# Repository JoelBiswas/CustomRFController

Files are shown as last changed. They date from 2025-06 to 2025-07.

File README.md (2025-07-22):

# Custom Star Wars RF Controller
This repository contains the files to build a custom RF controller in the shape of the Rebel Alliance Logo from Star Wars. The controller consists of two joysticks, six buttons, and is controlled by an ESP32. This project was created entirely by me for Hack Club's Highway to Undercity event. My plan is to test this device by using to control an [R2-D2 droid that I designed](https://github.com/JoelBiswas/r2d2/tree/main) for the same Hack Club event earlier this summer.

TopView

## Bill of Materials
View the Bill of Materials [here](https://docs.google.com/spreadsheets/d/1eimf_XqeCwkksVUzqHQLZJRxSmD6-AT-35apM8Ljc3Q/edit?usp=sharing)

Screenshot 2025-06-19 at 11 42 58 AM

## The Beginning
The idea for this project came after finishing my last project, an R2-D2 droid controlled with a PS3 controller. I thought that it would be interesting to make my own Star Wars-themed RF transmitter to control the droid with. I hoped that this would provide the robot with much greater range than a Bluetooth-based controller. This project felt perfect as I was looking to start a project that expands my electrical skills. My last project was heavily focused on CAD, so I wanted this project to be more focused on wiring schematic and PCB design. Like the droid, this project is also made for Hack Club's Highway to Undercity event, which provides high school students with grants to build their dream projects.

## About the Controller
The controller consists of two main parts: the PCB and the case. The PCB consists of an ESP32, two MP1584 buck converters, two KY-023 Joystick Modules, six push buttons, and an nRF24L01+ PA/LNA RF Module. It is powered by a 2S LiPo battery that connects to the PCB using a Deans Connector. The case is 3D-printable and houses the battery and PCB. The two joysticks are labeled LS and RS, and the buttons are labeled A, B, X, Y, 1, and 2. An antenna on the PCB extends up through a hole in the top of the case in order to transmit the RF signals.

## Overview of this Repo
**CAD** - Contains the CAD files for the controller, along with images taken from OnShape. <br>
**STLs** - Contains files for each part that needs to be 3D printed <br>
**Print** - Contains the 3d print files for the Flashforge Adventurer 5M <br>
**Electrical** - Contains files from KiCAD for the controller's wiring schematic, custom symbols, custom footprints, and PCB <br>
**Code** - Currently empty but will eventually contain the code for sending RF signals <br>
**JOURNAL.md** - Contains an overview of exactly how I designed and built this robot <br>
**BOM.csv** - A bill of materials for this project in CSV format <br>

## Designing the Robot
Click [here](https://cad.onshape.com/documents/af772411fd2681a1311b7be6/w/e5e3a94108ce63d65661e1b4/e/943c3c2dcbac8496e1ce6b2c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) to view the Onshape document for this project. The electronic design was done in KiCAD.

CAD
PCB

## General Steps for Assembly
1. 3D print each of the files in the STLs folder. The case top and bottom should be printed in orange PLA, and the button should be printed six times in black PLA.
2. Place the LiPo battery into the inserts in the case
3. Place the PCB over the battery on the standoffs. Plug the battery into the Deans connector on the PCB
4. Bolt in the top of the case using an M3 bolt on each side
5. Hot glue the 3D printed button onto the PCB buttons

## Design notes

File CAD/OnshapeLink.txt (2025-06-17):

https://cad.onshape.com/documents/af772411fd2681a1311b7be6/w/e5e3a94108ce63d65661e1b4/e/812a9f2dcd376fd01cbdf196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

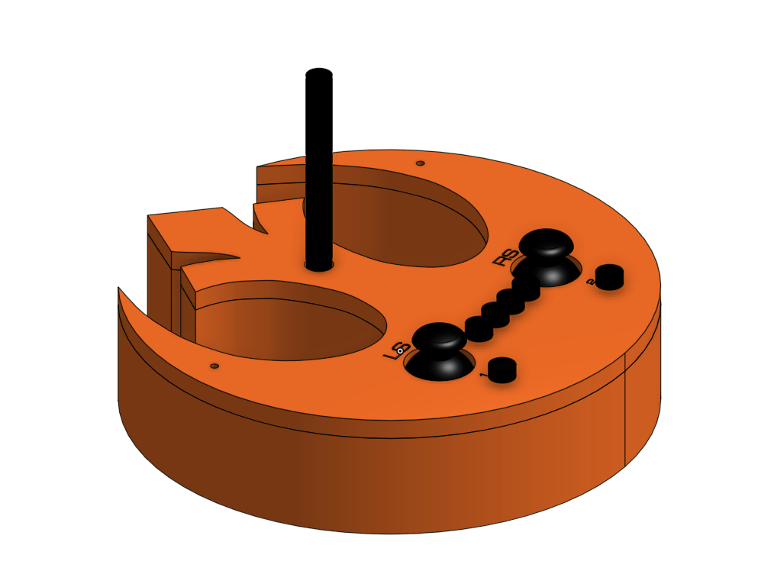
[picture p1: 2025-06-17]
CAD/Images/FrontLeftView.png

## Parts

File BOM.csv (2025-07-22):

Part | Quanitty | Unit Price | Price | Link | CAD Link
nRF24L01+ PA/LNA Radio Module | 1 | $7.99 | $7.99 | https://www.amazon.com/MakerFocus-NRF24L01-Transceiver-Antistatic-Compatible/dp/B01IK78PQA | https://grabcad.com/library/wireless-transceiver-module-2-4g-1100m-nrf24l01-pa-lna-1
ESP-WROOM-32 Microcontroller | 1 | $0.00 | $0.00 | N/A | https://grabcad.com/library/esp32-wroom-32d-devkit-ch340-usb-c-1
Button | 6 | $0.00 | $0.00 | N/A
Joystick | 1 | $6.29 | $6.29 | https://www.amazon.com/Joystick-Control-Sensor-Dual-Axis-Arduino/dp/B0DH2G1PVP?sr=1-5 | https://grabcad.com/library/ky-023-joystick-module-1
2S Lipo | 1 | $11.49 | $11.49 | https://www.amazon.com/OVONIC-Battery-Dean-Style-Connector-Vehicles/dp/B07T7GZ5C2?sr=8-16
MP1584EN Buck Convertor | 1 | $8.29 | $8.29 | https://www.amazon.com/AITRIP-MP1584EN-Converter-Adjustable-Supply/dp/B08DHS5XVK?sr=8-2 | https://grabcad.com/library/detailed-d-sun-mp1584en-dc-dc-step-down-voltage-regulator-1
Decoupling Capacitors | 1 | $9.99 | $9.99 | https://www.amazon.com/dp/B0C1V8Q93P
Male Connector Pins | 1 | $4.99 | $4.99 | https://www.amazon.com/MCIGICM-Header-2-45mm-Arduino-Connector/dp/B07PKKY8BX?sr=8-3
T Connectors | 1 | $6.99 | $6.99 | https://www.amazon.com/FLY-RC-T-Plug-Connectors-Battery/dp/B07BHCFXJZ?sr=8-2 | https://grabcad.com/library/t-plug-deans-connector-male-and-female-connector-1
PCB | 1 | $51.75 | $51.75 | https://cart.jlcpcb.com/quote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
Deburring Tool | 1 | $8.00 | $8.00 | https://www.amazon.com/Deburring-Tool-10Pcs-HSS-Blades/dp/B09376DFYP?sr=8-10
PCB Clamp | 1 | $13.40 | $13.40 | https://www.amazon.com/Noah-Adjustable-Soldering-Desoldering-Rotation/dp/B0CY4DRHWK?sr=8-6
 |  | Total
 |  | $129.18

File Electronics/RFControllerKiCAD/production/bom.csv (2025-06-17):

Designator | Footprint | Quantity | Value | LCSC Part #
5V TO 3.3V1, 7.4V TO 5V1 | MP1584_Module | 2 | ~
BT1 | Deans_Connector | 1 | 7.4V
C1 | C_Disc_D4.3mm_W1.9mm_P5.00mm | 1 | 10 uF
C2 | C_Disc_D4.3mm_W1.9mm_P5.00mm | 1 | 0.1 uF
ESP32 | ESP32_DevKitC_30 | 1 | ~
JOYSTICK1, JOYSTICK2 | KY-023_Module | 2 | ~
RADIO1 | NRF24L01_PA_LNA | 1 | ~
SW1, SW2, SW3, SW4, SW5, SW6 | SW_PUSH_6mm | 6 | SW_Push

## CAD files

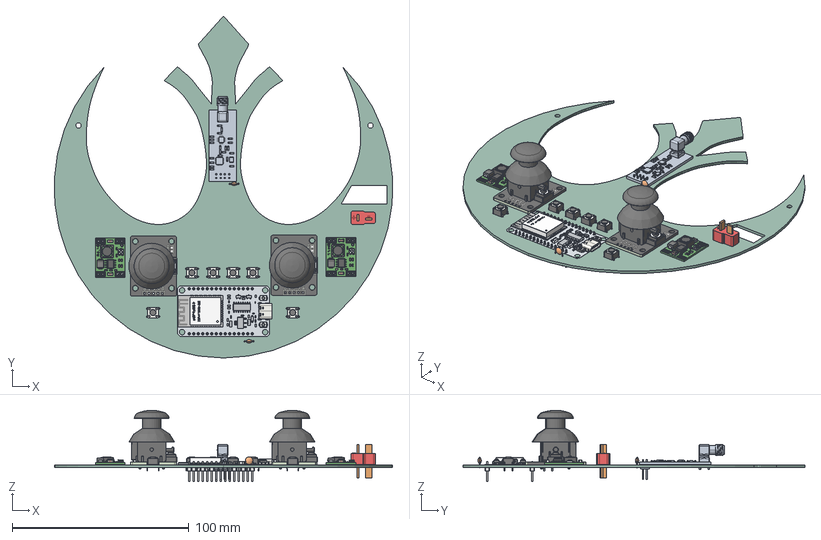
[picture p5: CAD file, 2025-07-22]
Electronics/PCB.step
191.3 x 193.3 x 40.3 mm
SW_PUSH_6mm x 6
main001 x 2
silk-TOP x 2
pins x 2
comp-top x 2
silk-bot x 2
PCB x 3
Thumb-Button x 2
Potentiometer_02 x 2
Baseplate x 2
Tactile-Switch x 2
Case x 2
Potentiometer_01 x 2
Rotator-Unit x 2
SOIC_16_39x99mm_P127mm
SOT_223
USB_C_Receptacle_16P_TopMnt_Horizontal_GCT_USB4105-xx-A
USB_C_Receptacle_16P_TopMnt_Horizontal_GCT_USB4105-xx-A001
USB_C_Receptacle_16P_TopMnt_Horizontal_GCT_USB4105-xx-A002
USB_C_Receptacle_16P_TopMnt_Horizontal_GCT_USB4105-xx-A003
USB_C_Receptacle_16P_TopMnt_Horizontal_GCT_USB4105-xx-A004
USB_C_Receptacle_16P_TopMnt_Horizontal_GCT_USB4105-xx-A005
USB_C_Receptacle_16P_TopMnt_Horizontal_GCT_USB4105-xx-A006
USB_C_Receptacle_16P_TopMnt_Horizontal_GCT_USB4105-xx-A007
USB_C_Receptacle_16P_TopMnt_Horizontal_GCT_USB4105-xx-A008
USB_C_Receptacle_16P_TopMnt_Horizontal_GCT_USB4105-xx-A009
USB_C_Receptacle_16P_TopMnt_Horizontal_GCT_USB4105-xx-A010
USB_C_Receptacle_16P_TopMnt_Horizontal_GCT_USB4105-xx-A011
USB_C_Receptacle_16P_TopMnt_Horizontal_GCT_USB4105-xx-A012
USB_C_Receptacle_16P_TopMnt_Horizontal_GCT_USB4105-xx-A013
USB_C_Receptacle_16P_TopMnt_Horizontal_GCT_USB4105-xx-A014
USB_C_Receptacle_16P_TopMnt_Horizontal_GCT_USB4105-xx-A015
USB_C_Receptacle_16P_TopMnt_Horizontal_GCT_USB4105-xx-A016
USB_C_Receptacle_16P_TopMnt_Horizontal_GCT_USB4105-xx-A017
USB_C_Receptacle_16P_TopMnt_Horizontal_GCT_USB4105-xx-A018
USB_C_Receptacle_16P_TopMnt_Horizontal_GCT_USB4105-xx-A019
USB_C_Receptacle_16P_TopMnt_Horizontal_GCT_USB4105-xx-A020
USB_C_Receptacle_16P_TopMnt_Horizontal_GCT_USB4105-xx-A021
USB_C_Receptacle_16P_TopMnt_Horizontal_GCT_USB4105-xx-A022
USB_C_Receptacle_16P_TopMnt_Horizontal_GCT_USB4105-xx-A023
USB_C_Receptacle_16P_TopMnt_Horizontal_GCT_USB4105-xx-A024
USB_C_Receptacle_16P_TopMnt_Horizontal_GCT_USB4105-xx-A025
USB_C_Receptacle_16P_TopMnt_Horizontal_GCT_USB4105-xx-A026
USB_C_Receptacle_16P_TopMnt_Horizontal_GCT_USB4105-xx-A027
USB_C_Receptacle_16P_TopMnt_Horizontal_GCT_USB4105-xx-A028
USB_C_Receptacle_16P_TopMnt_Horizontal_GCT_USB4105-xx-A029
USB_C_Receptacle_16P_TopMnt_Horizontal_GCT_USB4105-xx-A030
USB_C_Receptacle_16P_TopMnt_Horizontal_GCT_USB4105-xx-A031
USB_C_Receptacle_16P_TopMnt_Horizontal_GCT_USB4105-xx-A032
USB_C_Receptacle_16P_TopMnt_Horizontal_GCT_USB4105-xx-A033
USB_C_Receptacle_16P_TopMnt_Horizontal_GCT_USB4105-xx-A034
USB_C_Receptacle_16P_TopMnt_Horizontal_GCT_USB4105-xx-A035
LED_0603_D2
LED_0603_PWR
SOT_23_1
SOT_23_002
D_SOD_123
R_0603_
R_0603_001
R_0603_002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

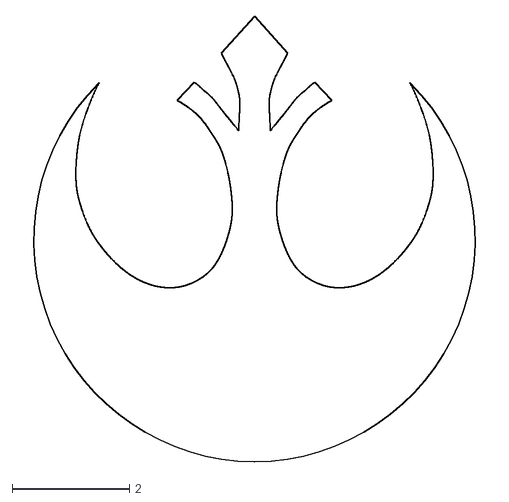
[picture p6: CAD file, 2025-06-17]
Electronics/RFControllerKiCAD/KiCADExtra/TestEdge.dxf
8.13 x 7.61

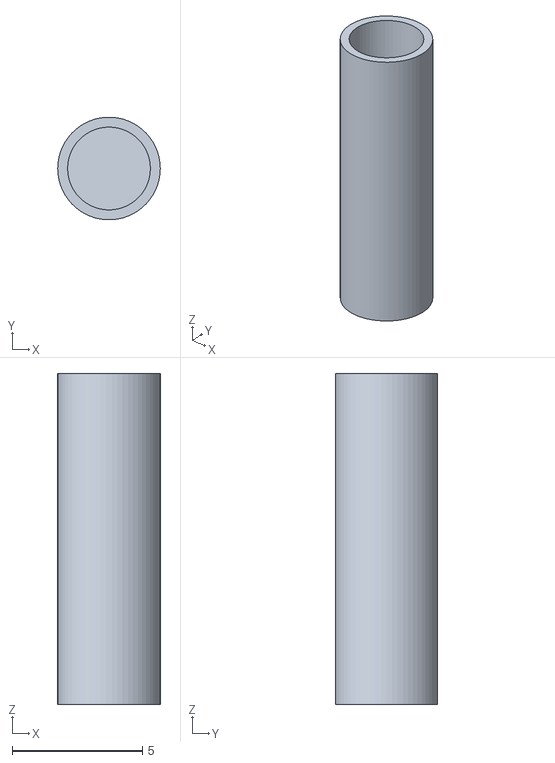
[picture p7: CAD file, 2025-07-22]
STLs/ButtonBase.stl
3.94 x 3.93 x 12.7

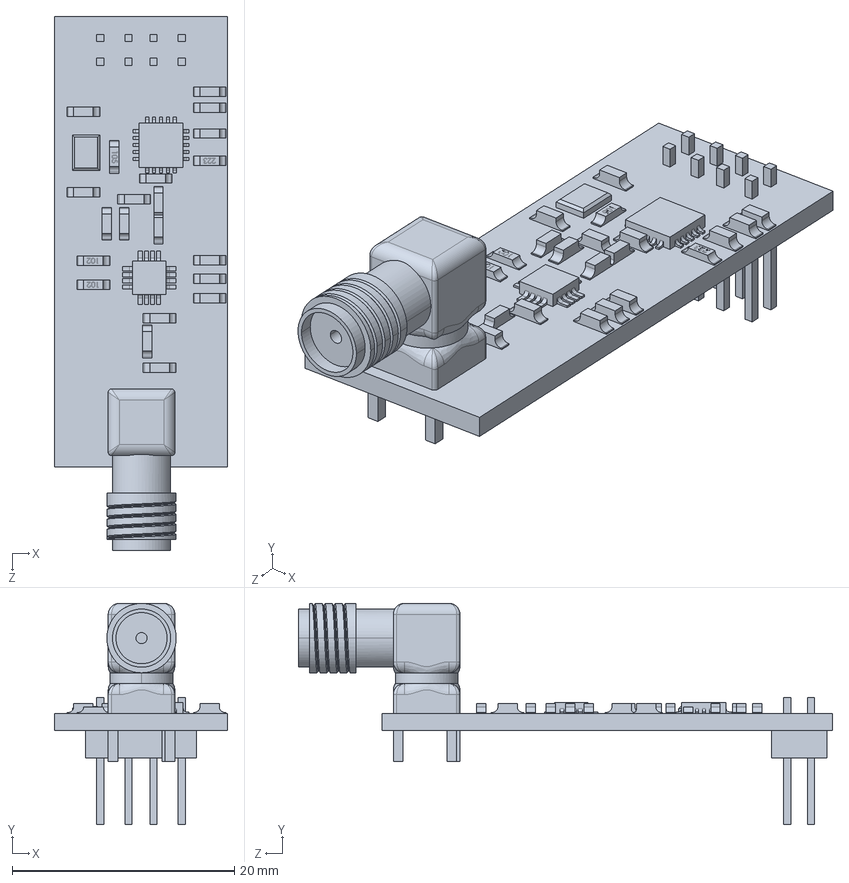
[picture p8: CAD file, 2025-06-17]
Electronics/RFControllerKiCAD/KiCADExtra/nRF24L01.STEP
15.6 x 19.9 x 48.0 mm

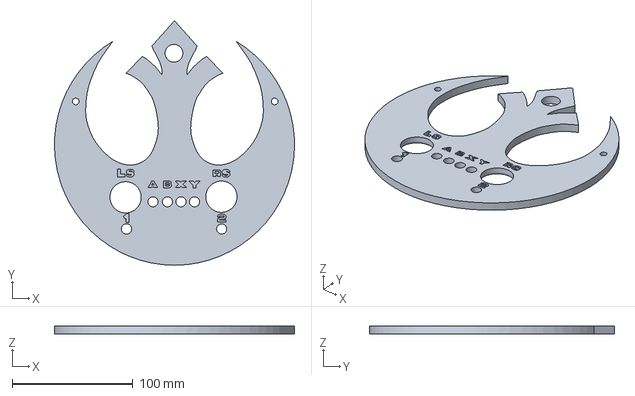
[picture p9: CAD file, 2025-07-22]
Print/ControllerTop.3mf
199.1 x 202.8 x 6.60 mm

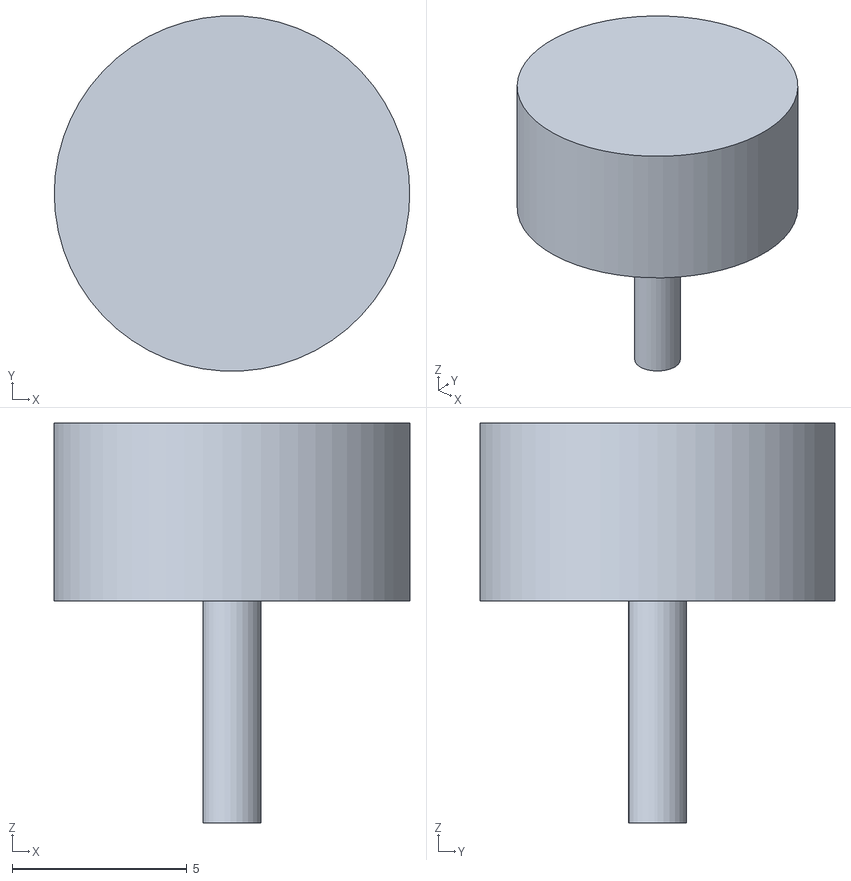
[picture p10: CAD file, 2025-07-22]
STLs/ButtonTop.stl
10.2 x 10.1 x 11.4

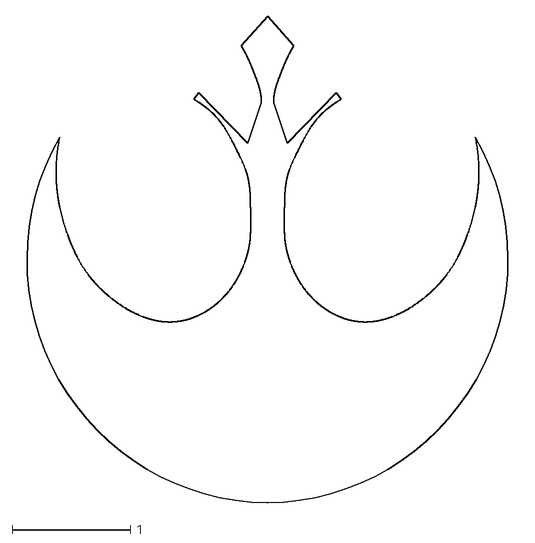
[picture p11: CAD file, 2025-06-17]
Electronics/RFControllerKiCAD/KiCADExtra/PCB Edge.dxf
4.26 x 4.12

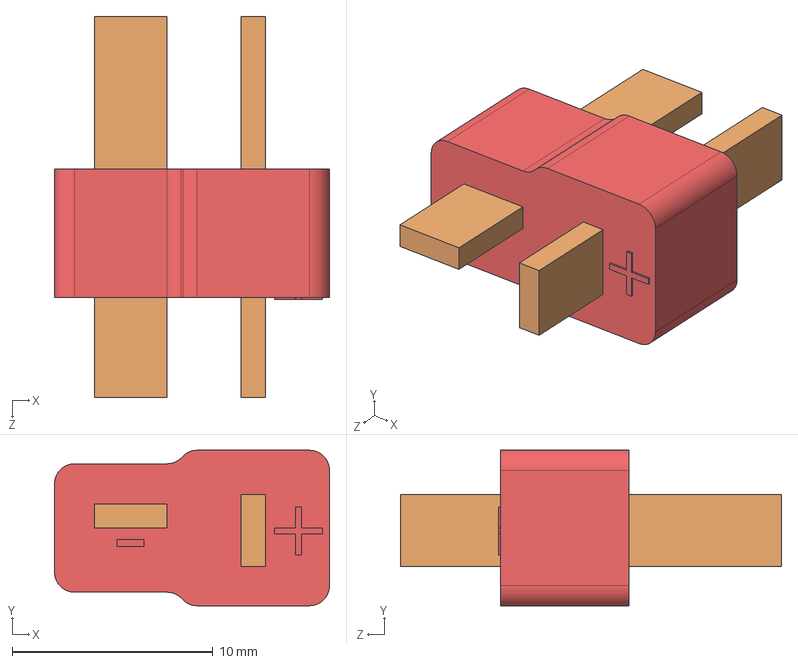
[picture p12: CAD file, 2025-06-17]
Electronics/RFControllerKiCAD/KiCADExtra/MaleTPlug.STEP
13.7 x 7.75 x 19.0 mm

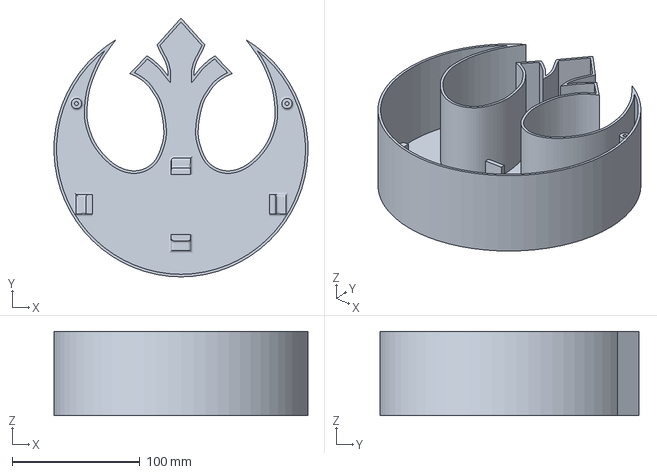
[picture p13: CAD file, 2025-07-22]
Print/ControllerBase.3mf
199.1 x 202.8 x 66.0 mm

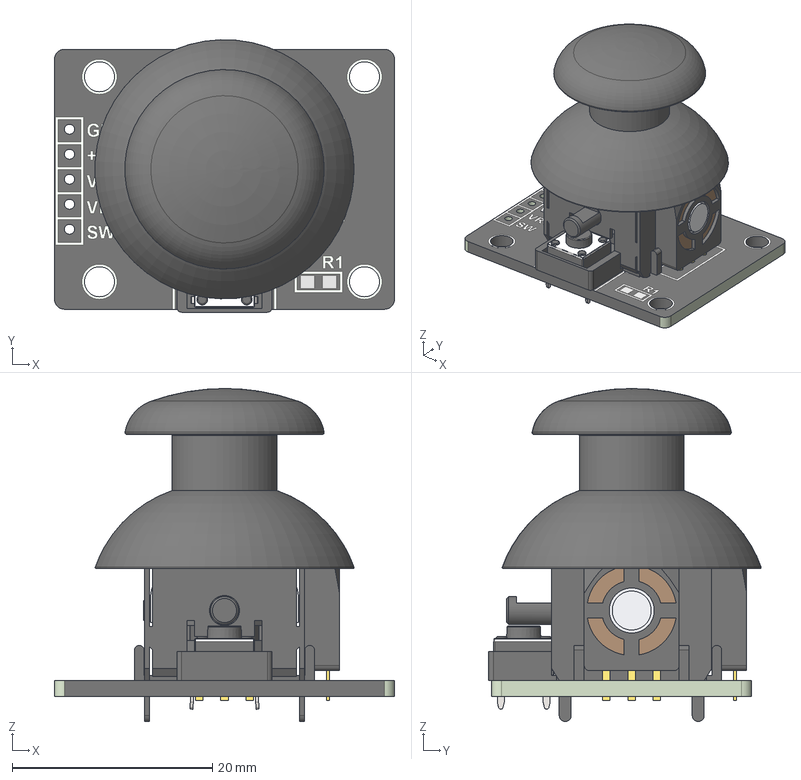
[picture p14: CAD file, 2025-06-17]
Electronics/RFControllerKiCAD/KiCADExtra/KY-023.step
34.0 x 27.3 x 33.3 mm
PCB
Thumb-Button
Potentiometer_02
Baseplate
Tactile-Switch
Case
Potentiometer_01
Rotator-Unit

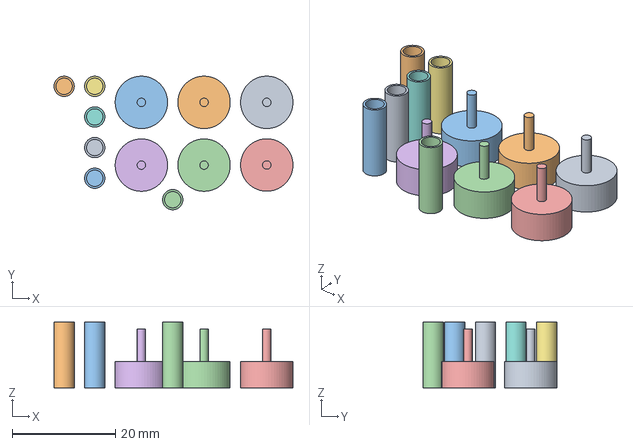
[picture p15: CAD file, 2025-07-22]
Print/Buttons.3mf
46.3 x 25.9 x 12.7 mm
ButtonTop.stl x 6
ButtonBase.stl x 6

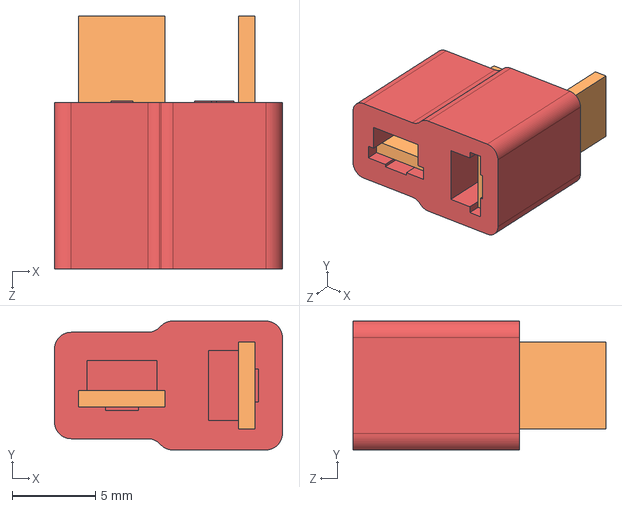
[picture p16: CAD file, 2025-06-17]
Electronics/RFControllerKiCAD/KiCADExtra/FemaleTPlug.STEP
13.7 x 7.75 x 15.2 mm

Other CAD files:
Print/ControllerTop.gcode.3mf
Print/Buttons.gcode.3mf
Print/ControllerBase.gcode.3mf
STLs/ControllerBase.stl
STLs/ControllerTop.stl

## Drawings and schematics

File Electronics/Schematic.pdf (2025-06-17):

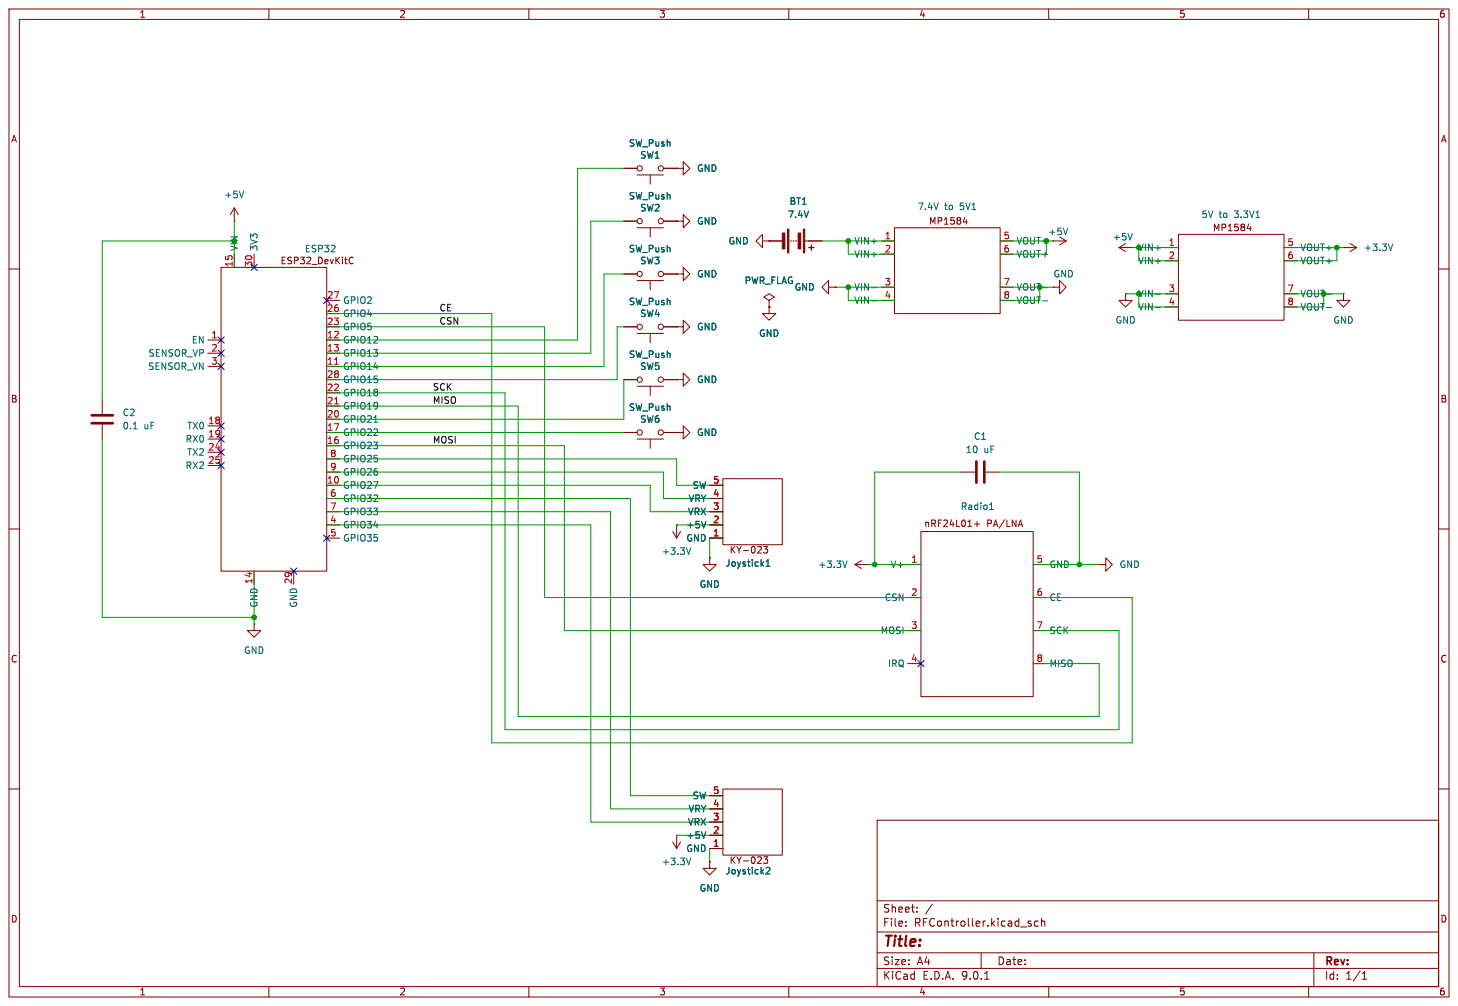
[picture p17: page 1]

SW4 SW_Push+3.3V GND
GND
Joystick1 GND 1 +5V 2 VRX 3 VRY 4 SW 5 GND

KY-023 GND 1 +5V 2 VRX 3 VRY 4 SW 5

Joystick2 GND 1 +5V 2 VRX 3 VRY 4 SW 5

Id: 1/1 Title: File: RFController.kicad_sch Sheet: /

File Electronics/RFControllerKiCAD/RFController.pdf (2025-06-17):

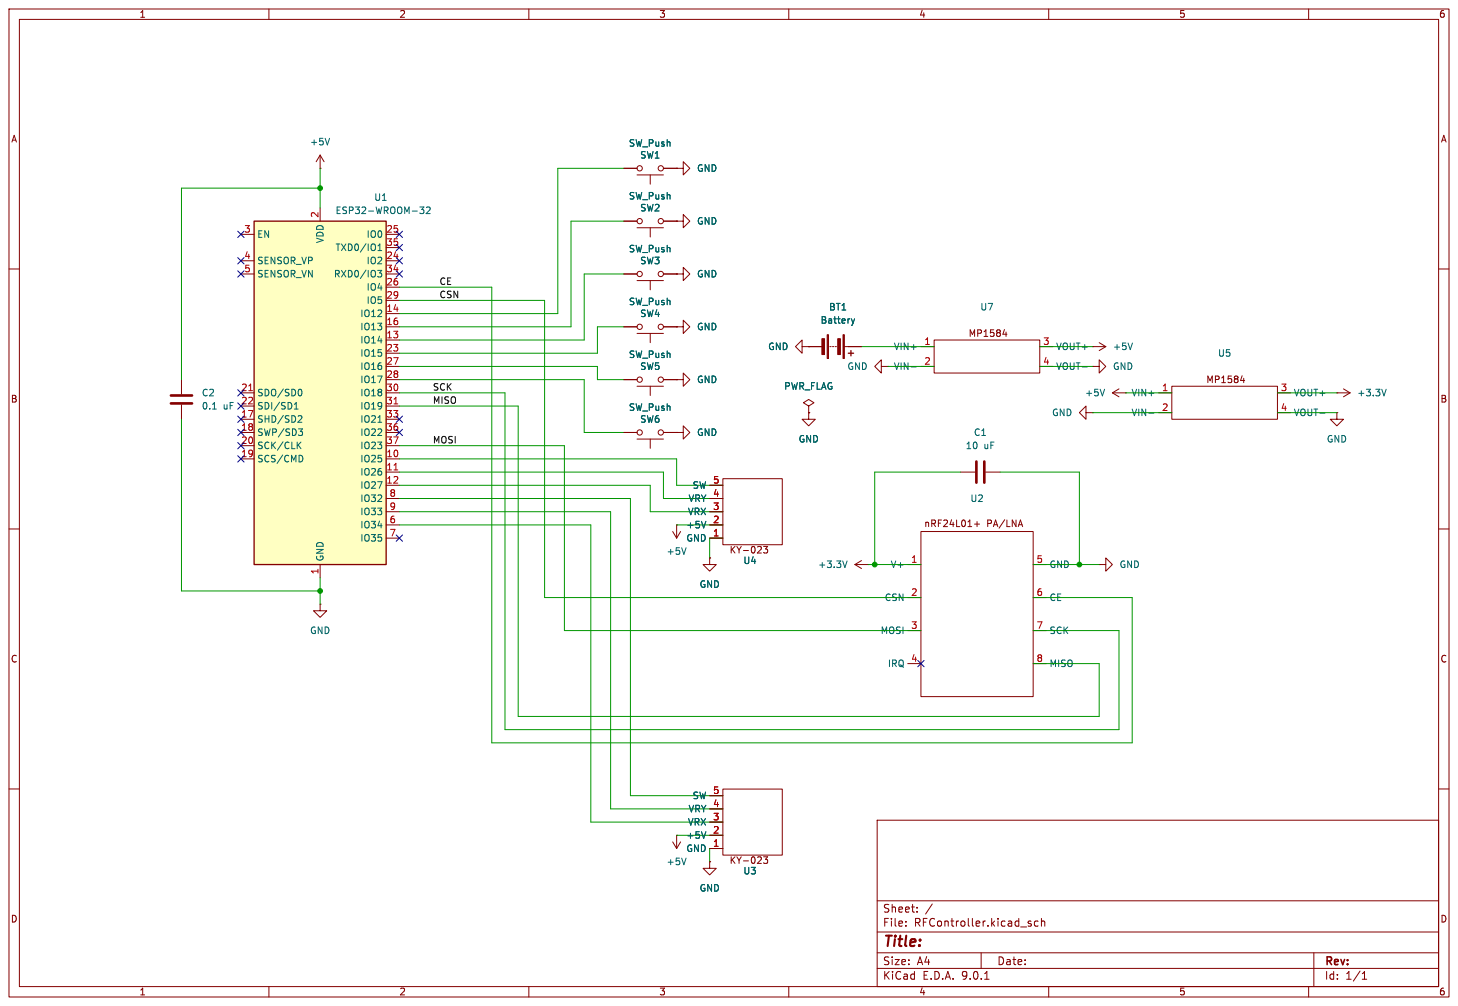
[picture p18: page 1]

U3 GND 1 +5V 2 VRX 3 VRY 4 SW 5 GND
U4 GND 1 +5V 2 VRX 3 VRY 4 SW 5 GND

SCK MOSI CECSN MISO

Id: 1/1 Title: File: RFController.kicad_sch Sheet: /

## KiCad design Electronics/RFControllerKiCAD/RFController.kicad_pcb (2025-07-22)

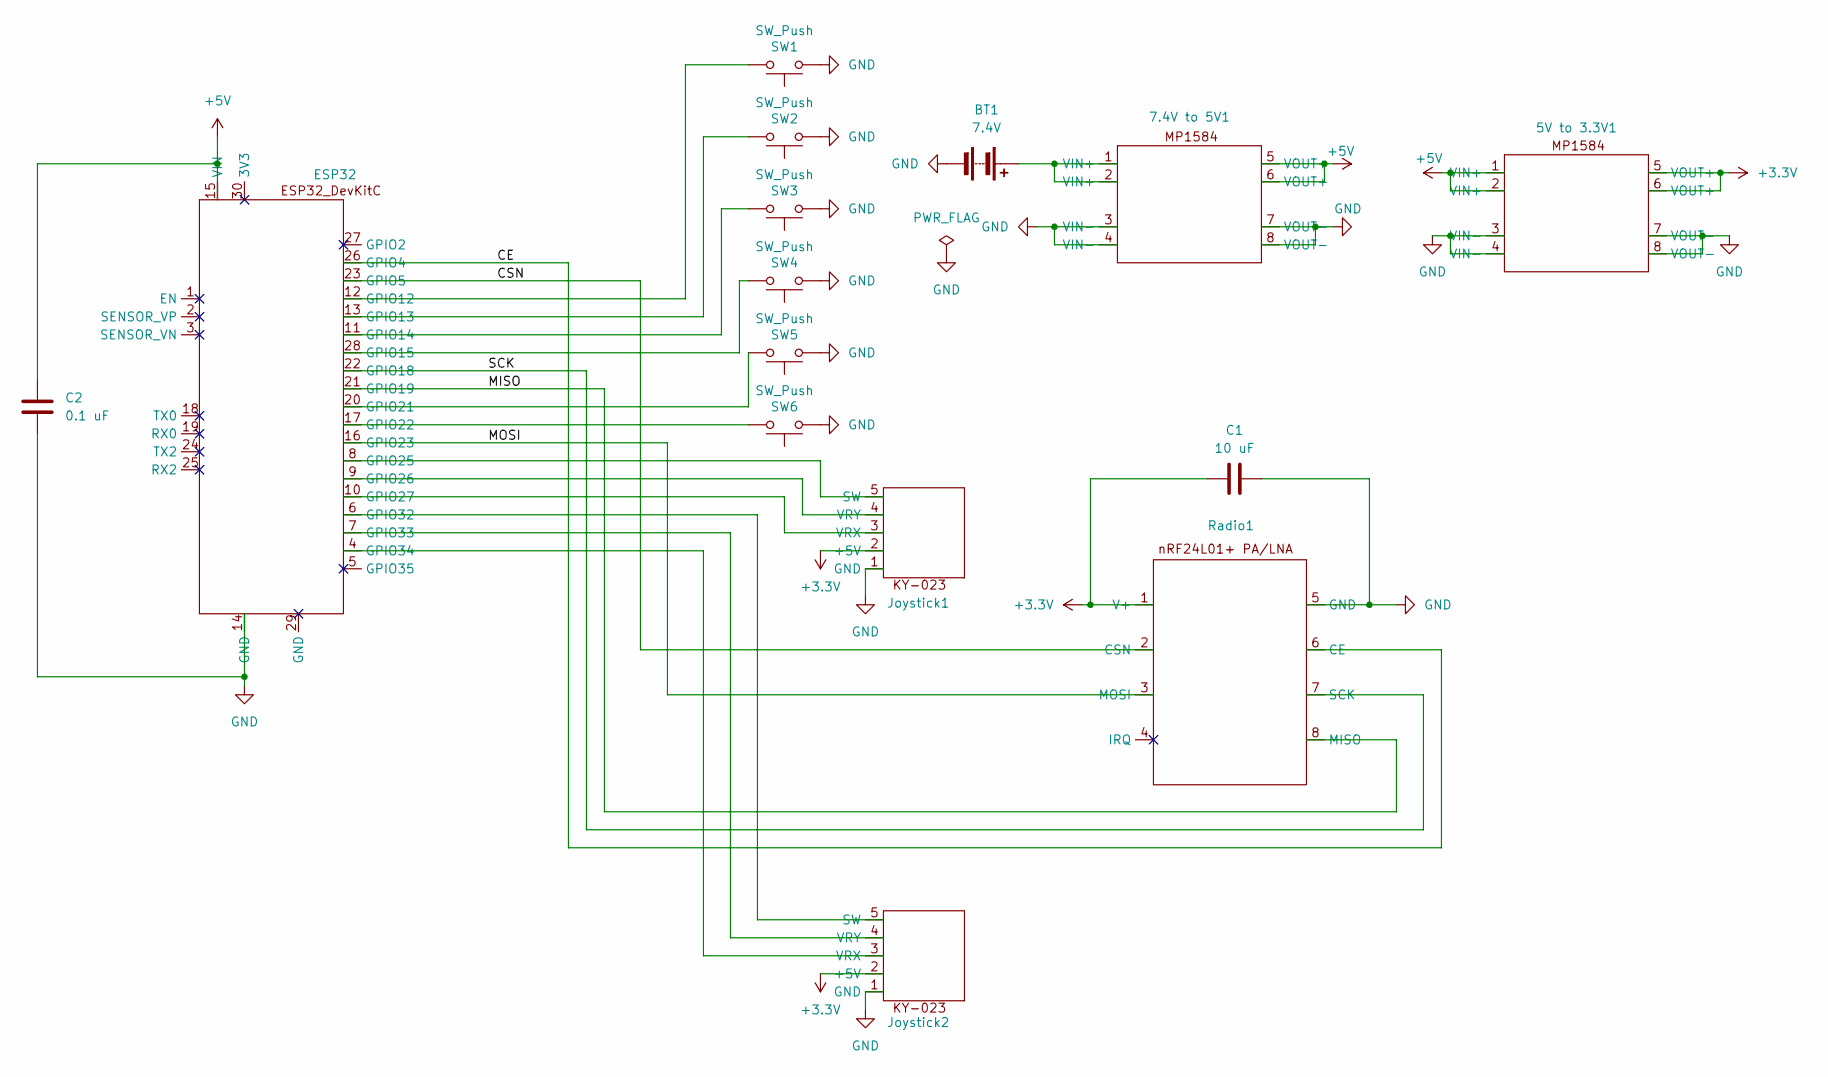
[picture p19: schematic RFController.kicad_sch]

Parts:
5V to 3.3V1, 7.4V to 5V1: MP1584_Module
BT1: 7.4V; Deans_Connector
C1: 10 uF; C_Disc_D4.3mm_W1.9mm_P5.00mm
C2: 0.1 uF; C_Disc_D4.3mm_W1.9mm_P5.00mm
ESP32: ESP32_DevKitC_30
Joystick1, Joystick2: KY-023_Module
Radio1: NRF24L01_PA_LNA
SW1, SW2, SW3, SW4, SW5, SW6: SW_Push; SW_PUSH_6mm

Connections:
+3.3V: 5V to 3.3V1.5 (VOUT+), 5V to 3.3V1.6 (VOUT+), C1.1, Joystick1.2 (+5V), Joystick2.2 (+5V), Radio1.1 (V+)
+5V: 5V to 3.3V1.1 (VIN+), 5V to 3.3V1.2 (VIN+), 7.4V to 5V1.5 (VOUT+), 7.4V to 5V1.6 (VOUT+), C2.1, ESP32.15 (VIN)
/CE: ESP32.26 (GPIO4), Radio1.6 (CE)
/CSN: ESP32.23 (GPIO5), Radio1.2 (CSN)
/MISO: ESP32.21 (GPIO19), Radio1.8 (MISO)
/MOSI: ESP32.16 (GPIO23), Radio1.3 (MOSI)
/SCK: ESP32.22 (GPIO18), Radio1.7 (SCK)
GND: 5V to 3.3V1.3 (VIN-), 5V to 3.3V1.4 (VIN-), 5V to 3.3V1.7 (VOUT-), 5V to 3.3V1.8 (VOUT-), 7.4V to 5V1.3 (VIN-), 7.4V to 5V1.4 (VIN-), 7.4V to 5V1.7 (VOUT-), 7.4V to 5V1.8 (VOUT-), BT1.2 (-), C1.2, C2.2, ESP32.14 (GND), Joystick1.1 (GND), Joystick2.1 (GND), Radio1.5 (GND), SW1.1, SW2.1, SW3.1, SW4.1, SW5.1, SW6.1
unnamed: 7.4V to 5V1.1 (VIN+), 7.4V to 5V1.2 (VIN+), BT1.1 (+)
unnamed: ESP32.12 (GPIO12), SW1.2
unnamed: ESP32.13 (GPIO13), SW2.2
unnamed: ESP32.11 (GPIO14), SW3.2
unnamed: ESP32.28 (GPIO15), SW4.2
unnamed: ESP32.20 (GPIO21), SW5.2
unnamed: ESP32.17 (GPIO22), SW6.2
unnamed: ESP32.8 (GPIO25), Joystick1.5 (SW)
unnamed: ESP32.9 (GPIO26), Joystick1.4 (VRY)
unnamed: ESP32.10 (GPIO27), Joystick1.3 (VRX)
unnamed: ESP32.6 (GPIO32), Joystick2.5 (SW)
unnamed: ESP32.7 (GPIO33), Joystick2.4 (VRY)
unnamed: ESP32.4 (GPIO34), Joystick2.3 (VRX)

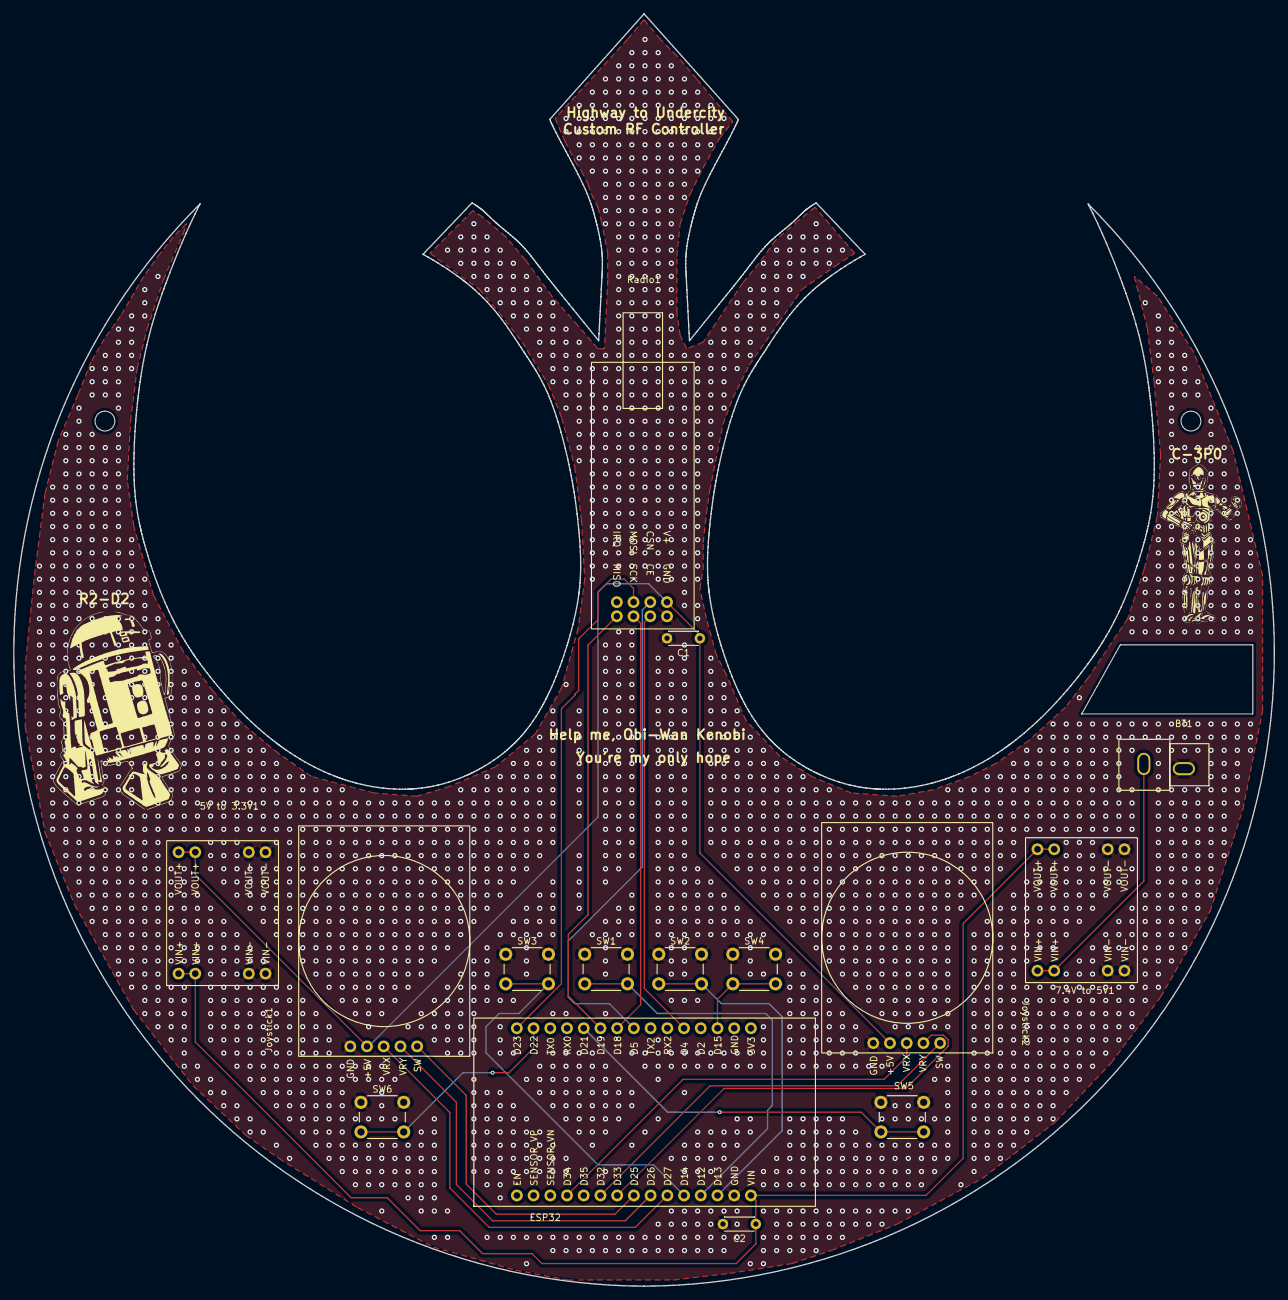
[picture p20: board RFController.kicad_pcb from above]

Board: 2 copper layers, 191.5 x 193.3 mm, 17 parts (0 on the bottom side), 21 nets.

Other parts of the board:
C-3P0: LOGO
R2-D2: LOGO

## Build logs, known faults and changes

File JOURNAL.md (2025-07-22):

---
title: "Custom RF Controller"
author: "Joel Biswas"
description: "Custom RF controller with two joysticks, two triggers, and four buttons"
created_at: "2025-06-10"
---

**Total Time Spent:** 29 hours

### DAY ONE - June 11, 2025
I spent today creating a wiring schematic for this project, as making an RC controller is fairly electrically intensive. The schematic uses an ESP32-DevKitC for the microcontroller, two KY-023 modules for the joysticks, two MP1584 modules for the buck converters, an nRF24l01+ PA/LNA module for the RF transmitter, six buttons, and a Deans Connector for the battery. Because KiCAD does not include modules in its symbol libraries, I had to create custom symbols for the ESP32-DevKitC, the KY-023, the MP1584, and the nRF24L01. I used one buck convertor to reduce the battery's 7.4V to 5V, and a second buck convertor to convert the 5V to 3.3V.

Day One Schematic
Day One Symbol

**Time Spent:** 8 hours

### DAY TWO - June 12, 2025
Today, I created custom footprints for 5 different comonenents on my PCB. This was my first time creating footprints, so it took me longer than expected. The first one was the most difficult: a footprint for the Deans Connector. This connector would allow the battery to connect to the PCB. I also created a footprint for the ESP32-DevKitC, the MP1584 module, the nRF24L01+ PA/LNA module, and the KY-023 module. I then found 3D STEP models for each of these components on grabcad, and added the models into KiCAD.

Day Two Deans
Day Two ESP

**Time Spent:** 6 hours

### DAY THREE - June 14, 2025
Today, I finally designed the PCB! I made a sketch of the PCB outline in OnShape, then exported the sketch as a DXF file and placed it into KiCAD, in the Edge.Cuts later. I then began positioning the components where I wanted them to be on the final design. I placed the ESP32 in the center, one joystick on each side, four buttons in the middle, and two buttons on the bottom. I also placed the RF module in the middle, so that the antenna could could extrude from the middle of the case. I used a ground pour on both sides to make sure that all components are correctly connected to ground. I then added all the necessary traces to finish the PCB

Day Three PCB
Day Three 3D PCB

**Time Spent:** 8 hours

### DAY FOUR - June 16, 2025
I spent today finishing the CAD model for the controller. I first imported the STEP file for the PCB from KiCAD into Onshape. I then designed a mount for the battery, standoffs for the PCB to be mounted to, and a top section to cover the electronics. I also designed 3D-printable buttons that could be hot-glued to the electronic buttons. These would allow the buttons to be pushed even when the electronics are covered up

Day Four Battery + Case
Day Four Electronics + Case

**Time Spent**: 5 hours

### DAY FIVE - June 17
Today, I finished setting up this GitHub repository. I added folders for the electrical files and design files. I also added an empty folder for code that will be added to after the controller is assembled. The project is noe ready to be shipped!

**Time Spent:** 2 hours

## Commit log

2025-07-22 Updated STLs
    [ControllerBase.stl, ControllerTop.stl, PCB.step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]
2025-07-22 Updated Print
    [ButtonBase.stl, ButtonTop.stl, Buttons.3mf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]
